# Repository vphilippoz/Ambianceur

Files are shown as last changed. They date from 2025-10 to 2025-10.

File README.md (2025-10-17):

# Ambianceur
Raspberry Pi based automated audio player. Use it in any room where you want to create an ambiance! 

I use this device plays ambiant sounds, such as forest, rain or wind recordings. The audio is started as soon as movement is detected, and ends 30 seconds after the movement stops. Also, the device remain silent at night.

# Required material
- Raspberry Pi 3B+ or newer, with an adapted power supply
- PIR sensor (for example, [BS412](https://www.adafruit.com/product/4666))
- Speaker with integrated amplifier (for example, [Adafruit STEMMA Speaker](https://www.adafruit.com/product/4666))
- A few cables, solder and a soldering iron
- Header socket (2.54 mm pitch) to connect peripherals to the Raspberry Pi. Alternatively, wires can be soldered directly to the board headers, but I would not recommand it.
    - 1x 01x01 pin configuration
    - 2x 01x02 pins configuration
- An old jack 3.5 mm cable that you are willing to destroy
- A 3D printer 
- 3D printing filament (~100g is necessary, depending on your slicing parameters)
- 3x M3 heat set threaded inserts
- 3x M3x5 socket head cap screws
- 8x M2.5x6 socket head cap screws
- Audio files you want to play in _.mp3_ format

# Instructions

## Setup the Raspberry Pi
1. Flash OS, setup Wifi, user and password (_pi_, _pipipipi_), etc.
1. Clone git repo in _/home/pi/Documents_
1. Install requirements : `sudo apt install python3-mypackage` for each package
1. Copy desired audio file(s) in _/home/pi/Music_
2. Disable the HDMI audio so the Jack 3.5 is used by default:
    1. Edit the configuration file: `sudo nano /boot/config.txt`
    2. Add the following:
       ```
       hdmi_ignore_edid_audio=1
       audio_pwm_mode=2
       ```
    4. Save and exit using _ctrl + X_
1. Autorun python script at boot using a _.desktop_ file (other methods such as _systemd_ do not work as the desktop env is required to play sound):
    1. Create the autostart directory: `mkdir -p /home/pi/.config/autostart`
    2. Create the file: `sudo nano /home/pi/.config/autostart/ambianceur.desktop`
    3. Enter the following in the file:
        ```
        [Desktop Entry]
        Type=Application
        Exec=python /home/pi/Documents/Ambianceur/main.py
        ```
    5. Save and exit using _ctrl + X_

## Printing the case
Any 3D printer can be used to print the case. I used an Ender 3 V3 with PETG filament.

1. Download the 3D files in _.stl_ format located in _Ambianceur/3D/_
1. Open your slicing software and import the files
1. Slice the file using your prefered parameters. I used 0.2 mm layer height and 2 wall perimeters.
1. Start printing!

## Soldering the electronics
Connect as follow:

**PIR:** 
- GND (VSS) and ONTIME -> 01x01 header socket. Will connect to pin 20 of Raspberry Pi (GND)
- VDD -> one pin of 01x02 header socket #1. Will connect to pin 17 of Raspberry Pi (3.3V)
- REL -> other pin of 1x02 header socket #1. Will connect to pin 18 of Raspberry Pi (GPIO 24)

**Audio amplifier:**
- +5V -> one pin of 01x02 header socket #2. Will connect to pin 4 of Raspberry Pi (5V)
- GND -> other pin of 01x02 header socket #2. Will connect to pin 6 of Raspberry Pi (GND)
- Jack 3.5mm GND -> GND pad on audio amplifier
- Jack 3.5mm Signal -> Signal pad on audio amplifier

## Assembly
1. Insert PIR sensor in the intended hole. If it is loose, use some glue, tape or similar to keep it in place.
1. Screw the audio amplifier board using four M2.5x6 screws.
1. Wire everything as explained in the previous section
1. Screw the Raspberry Pi using the remaining M2.5x6 screws.
1. Plug the power supply to the Raspberry Pi through the intended hole.
1. Screw the cover using three M3x5 screws

## Testing
Plug the power supply into a wall outlet. After less than 5 minutes, the device should be operationnal. Have fun!

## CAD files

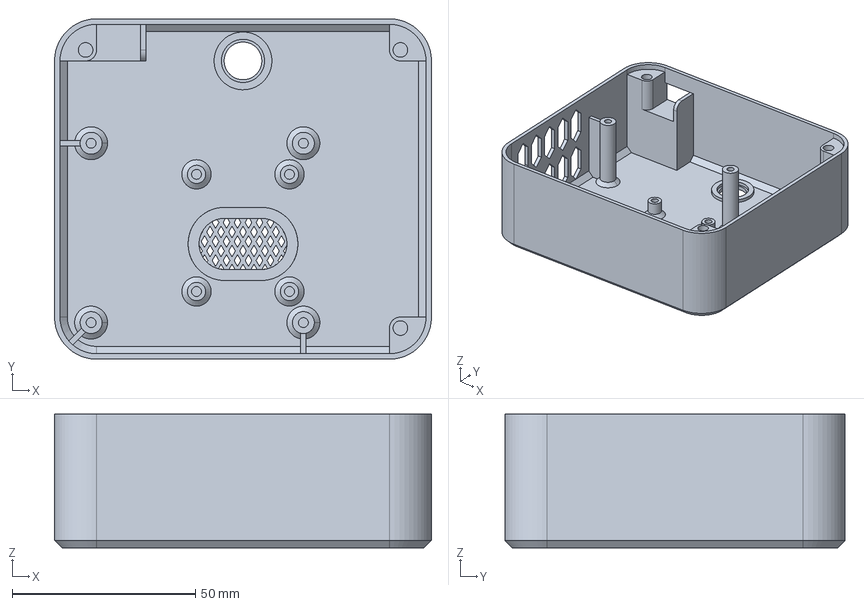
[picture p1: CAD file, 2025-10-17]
3D/case_top.FCStd
103.0 x 93.0 x 36.5 mm

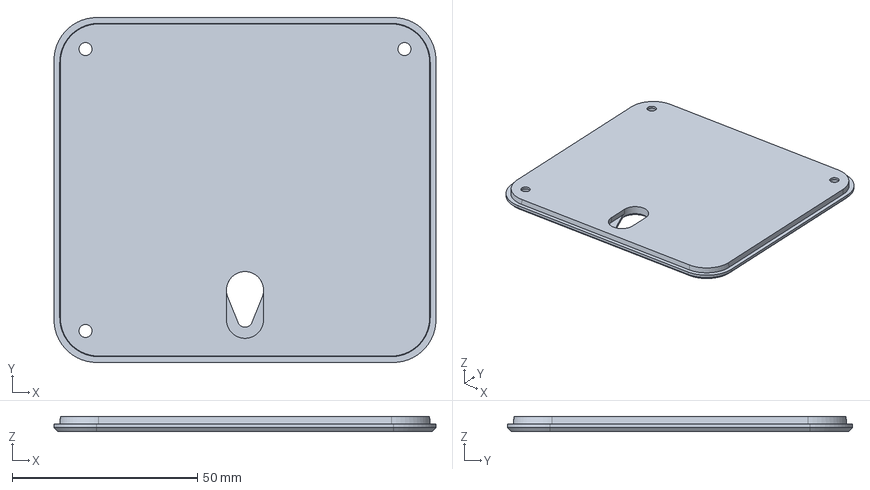
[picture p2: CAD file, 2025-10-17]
3D/case_bottom.FCStd
103.0 x 93.0 x 4.00 mm

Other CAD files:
3D/assembly.FCStd
3D/case_bottom.stl
3D/case_top.3mf
3D/case_top.stl

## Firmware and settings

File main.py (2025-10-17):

import time
import parameters as p
import music, sensor

def initialize() -> None:
    """
    Set up motion detection and audio playback.
    """
    sensor.initialize()
    music.initialize()

def main_loop() -> None:
    """
    Main program loop.

    Reads the motion sensor and controls music playback based on motion detection and time constraints.
    """
    music_start_time: float = 0 # [s]
    start_music: bool = False
    last_motion_time: float = 0 # [s]
    try:
        while True:
            # Read the motion sensor
            if sensor.read_motion_sensor() == True: 
                last_motion_time: float = time.time()
                start_music = True

            if music.is_playing():
                # Check if music should be stopped
                motionless_time: float = time.time() - last_motion_time
                play_time: float = time.time() - music_start_time

                if motionless_time > p.MIN_MOTIONLESS_TIME and play_time > p.MIN_PLAY_TIME:
                    music.stop()
            else:
                # Check if music should be started
                daytime: bool = p.EARLIEST_SOUND <= time.localtime().tm_hour + time.localtime().tm_min/60.0 < p.LATEST_SOUND
                if start_music and daytime:
                    music_start_time = music.play(music.load())
                    start_music = False

            time.sleep(p.PERIOD)
            start_music = False # Do not memorise detection for next loop

    except KeyboardInterrupt:
        if p.VERBOSE: print("Exiting program")
    finally:
        sensor.finalize()
        music.finalize()

if __name__ == "__main__":
    initialize()
    main_loop()

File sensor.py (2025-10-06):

import RPi.GPIO as GPIO
import parameters as p

def initialize() -> None:
    """
    Initialize the motion sensor.
    """
    GPIO.setmode(GPIO.BOARD)
    GPIO.setup(p.MOTION_SENSOR_PIN, GPIO.IN)

def finalize() -> None:
    """
    Finalize the motion sensor.
    """
    GPIO.cleanup()

def read_motion_sensor() -> bool:
    """
    Read the motion sensor.

    Return true if motion is detected, false otherwise.
    """
    return GPIO.input(p.MOTION_SENSOR_PIN)

# def motion_handler() -> None:
#     """
#     Handle motion detection.
#     """
#     global last_motion_time
#     last_motion_time = time.time()

#     if p.VERBOSE: print("Motion Detected!")

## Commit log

2025-10-06 Created sensor module
2025-10-09 Updated readme with current doc state
2025-10-10 Added material to README
2025-10-14 Added 3D models for enclosure
    [assembly.FCStd, case_bottom.FCStd, case_top.FCStd]
2025-10-15 Interference RPi USB solved
    [case_top.FCStd, case_top.stl]
2025-10-15 Fine adjustment of 3D model
    [case_top.FCStd, case_top.stl]
2025-10-16 Final modification of 3D box
    [case_bottom.FCStd, case_bottom.stl, case_top.FCStd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]
2025-10-17 Taking minutes into account for nightime calculation
    [case_top.3mf]
